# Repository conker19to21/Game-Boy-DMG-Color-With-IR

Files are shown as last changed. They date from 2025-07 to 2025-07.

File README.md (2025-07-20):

This Board is a modified version of <a href="https://github.com/MouseBiteLabs/Game-Boy-DMG-Color/tree/main/DMGC-CPU-01">Bucket Mouse's Original DMGC CPU board</a> which houses the majority of the electronics in the DMGC but adds the IR components and capability as well.

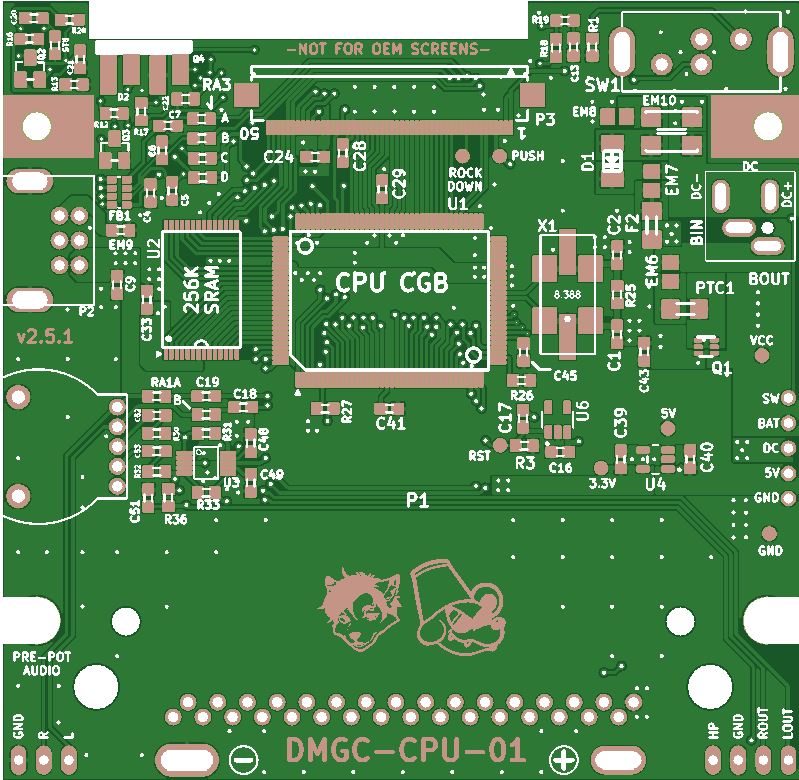
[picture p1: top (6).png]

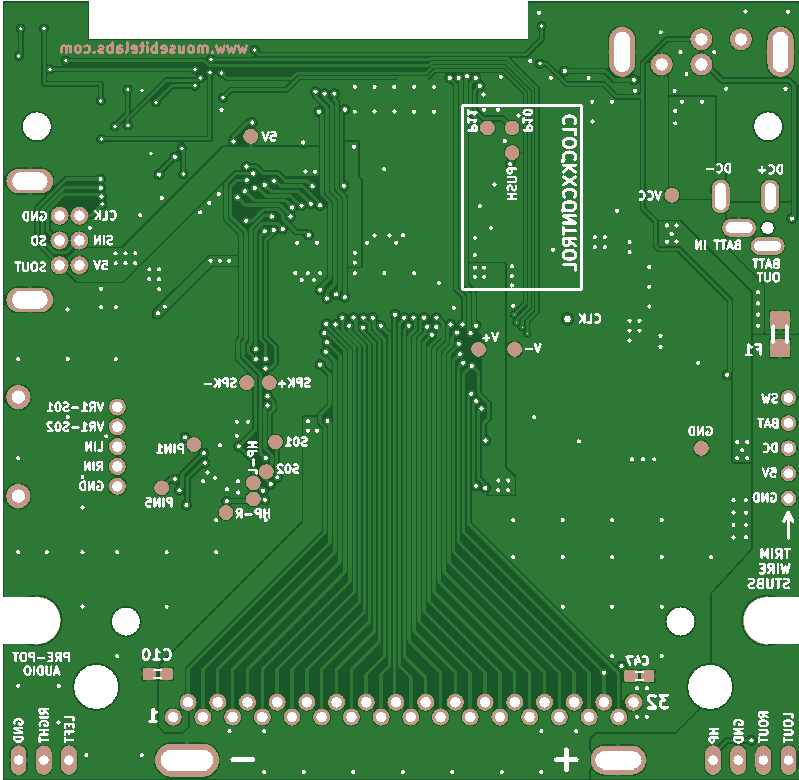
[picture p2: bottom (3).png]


Shoutout to NatalieTheNerd for their amazing Reverse engineering work which was referrenced for this project and can be <a href="https://github.com/nataliethenerd/CGB_ReverseEngineer/tree/main">Found Here!</a>

Additional Major Shout Out goes to EdvinDraw!
A IR shield cutout was designed by EdvinDraw and can be <a href="https://www.thingiverse.com/thing:7093936">Found Here!</a> for use with NON clear DMG shells.

Additionally EdvinDraw had also made a Tutorial how to use and make the IR shield cutout which can be <a href="https://youtu.be/QVl8f0OApuU?si=GgzmjaVQX5JkgJGN">Found Here!</a>

Also note the IR was tested on some clear shells and worked fine without the cutout or IR shield but may still be needed for some.

Download and use the gerber.zip file at your preferred PCB manufacture and use these Board Characteristics for proper fitment.
## Board Characteristics
The gerber zipped folder contains all the gerber files for this board. 

-	Layers: 2
-	Thickness: 1.2 mm
-	Surface Finish: ENIG or HASL
-   **NOTE: When ordering PCBs, add this note to the order: "The file PTH-drl.gbr contains outlines for plated slots. Please add plated slots on the PCB according to this layer."**

*HASL will work, but will potentially be more difficult for soldering fine-pitch parts like the CPU and FFC connector.*

I do not take any credit for Bucket Mouse's Board Design only the modifications done and implementation for the IR components which were added to it.

Be sure to check out Bucket Mouse's Original Github Post on the DMGC project which can be <a href="https://github.com/MouseBiteLabs/Game-Boy-DMG-Color/tree/main">Found Here!</a> and has a Huge breakdown of common issues and solutions to most issues which may occur during the building process.

Version 2.0 of Bucket Mouse's original design introduced a test pad labelled "RST" that connects directly to the /RESET pin. If this pin is pulled to GND, when it's released then the system will reset back to the boot screen. If you wire this pad to a button that connects the pad to GND when pressed, you basically have added a reset button to your DMGC. 

There are also pads near the FFC connector that are added labelled "PUSH" and "ROCK DOWN". These connect to the rocker switch on the DMGC-IPS-01 board (version 2.0 and later). The PUSH pad becomes connected to GND when the rocker switch is pushed in and floats when not pressed (as long as you remove R10 on the DMGC-IPS-01 board). The ROCK_DOWN pad connects to GND when the rocker switch is rocked down, and floats when not pressed (as long as you remove C5 on the DMGC-IPS-01 board).

In a normal configuration, pushing in on the rocker switch will control the button LEDs, and rocking down will swap the Q5 color settings, but if you don't want to use one of these features, then adding a wire from the PUSH or ROCK DOWN pad to RST pad will turn the rocker switch into a reset button for the system for that specific action and replace its normal function.

**CAUTION: Remember to remove R10 or C5 on the IPS board if you plan to use this feature!!!**





## Bill of Materials

Here, I have provided links to components I used personally (or suitable replacements). This BOM is also included in Excel format in the root folder.

| Reference Designators | Qty | Value/Part Number | Package | Description | Comment | Source |
| --- | --- | --- | --- | --- | --- | --- |
| +,- | 2 | | | Battery terminals  | Can be salvaged from DMG instead | [https://retrogamerepairshop.com/collections/dmg-power/products/game-boy-dmg-original-high-quality-replacement-battery-contact-terminals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](https://retrogamerepairshop.com/collections/dmg-power/products/game-boy-dmg-original-high-quality-replacement-battery-contact-terminals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) |
| C1 | 1 | 18pF | 0603 | Capacitor (MLCC) | Should be X5R (or better); at least 1% tolerance; at least 16V | [https://www.mouser.com/ProductDetail/YAGEO/CC0603FRNPO9BN180?qs=vTakOoo5QyL0KzYUzHPSUw%3D%3D](https://www.mouser.com/ProductDetail/YAGEO/CC0603FRNPO9BN180?qs=vTakOoo5QyL0KzYUzHPSUw%3D%3D) |
| C2 | 1 | 27pF | 0603 | Capacitor (MLCC) | Should be X5R (or better); at least 1% tolerance; at least 16V | [https://www.mouser.com/ProductDetail/603-C0603FRNPO9BN270](https://www.mouser.com/ProductDetail/603-C0603FRNPO9BN270) |
| C4 | 1 | 22pF | 0603 | Capacitor (MLCC) | | [https://www.mouser.com/ProductDetail/YAGEO/CC0603JRNPO9BN220?qs=vTakOoo5QyIVMYOUTI%2F4zA%3D%3D](https://www.mouser.com/ProductDetail/YAGEO/CC0603JRNPO9BN220?qs=vTakOoo5QyIVMYOUTI%2F4zA%3D%3D) |
| C5, C6, C7 | 3 | 100pF | 0603 | Capacitor (MLCC) | | [https://www.mouser.com/ProductDetail/YAGEO/CC0603JPNPO9BN101?qs=7s%252B3O6pAiyAo%2FUxNqKltRA%3D%3D](https://www.mouser.com/ProductDetail/YAGEO/CC0603JPNPO9BN101?qs=7s%252B3O6pAiyAo%2FUxNqKltRA%3D%3D) |
| C9, C10, C29, C33, C41, C45 | 6 | 0.01uF | 0603 | Capacitor (MLCC) | Should be X5R (or better), at least 16V | [https://www.mouser.com/ProductDetail/KEMET/C0603C103J5RACTU?qs=BimOss5pjlFJEfKhlb7g1g%3D%3D](https://www.mouser.com/ProductDetail/KEMET/C0603C103J5RACTU?qs=BimOss5pjlFJEfKhlb7g1g%3D%3D) |
| C16, C17, C18, C19, C39, C40, C48, C49, C51 | 9 | 1uF | 0603 | Capacitor (MLCC) | Should be X5R (or better), at least 16V | [https://www.mouser.com/ProductDetail/KEMET/C0603C105K4RACTU?qs=STjISULpmtZNMAZGR4X39Q%3D%3D](https://www.mouser.com/ProductDetail/KEMET/C0603C105K4RACTU?qs=STjISULpmtZNMAZGR4X39Q%3D%3D) |
| C24, C28, C43, C52, C53 | 5 | 0.1uF | 0603 | Capacitor (MLCC) | Should be X5R (or better), at least 16V | [https://www.mouser.com/ProductDetail/?qs=l5k%252BbMnNDknCtKnMv1oEgA%3D%3D](https://www.mouser.com/ProductDetail/?qs=l5k%252BbMnNDknCtKnMv1oEgA%3D%3D) |
| C47 | 1 | 150pF | 0603 | Capacitor (MLCC) | | [https://www.mouser.com/ProductDetail/KEMET/C0603C151J5GACTU?qs=V6nSPVTm7vxbAvL0weNH%252BQ%3D%3D](https://www.mouser.com/ProductDetail/KEMET/C0603C151J5GACTU?qs=V6nSPVTm7vxbAvL0weNH%252BQ%3D%3D) |
| D1 | 1 | PMEG2010AEH | SOD-123 | Schottky diode | Most schottky diodes should be suitable (at least 1A, 16V) | [https://www.mouser.com/ProductDetail/?qs=LOCUfHb8d9u7lcjEnyhX1g%3D%3D](https://www.mouser.com/ProductDetail/?qs=LOCUfHb8d9u7lcjEnyhX1g%3D%3D) |
| DC | 1 | | | DC jack | | Salvaged (DMG) |
| EM6-EM8 | 3 | FBMH2012HM221-T | 0805 | Filter | | https://mou.sr/3YT6y8F |
| EM9 | 1 | BLM18BD102SN1D | 0603 | Filter | | [https://www.mouser.com/ProductDetail/Murata-Electronics/BLM18BD102SN1D?qs=h3IWXJJGQQWi4eZyJq6ScQ%3D%3D](https://www.mouser.com/ProductDetail/Murata-Electronics/BLM18BD102SN1D?qs=h3IWXJJGQQWi4eZyJq6ScQ%3D%3D) |
| EM10 | 1 | 744235601 | | Common mode filter | Can be salvaged from GBC instead | [https://www.mouser.com/ProductDetail/Wurth-Elektronik/744235601?qs=BXmE%252BJ0Y7xYO4MPd53j2NQ%3D%3D](https://www.mouser.com/ProductDetail/Wurth-Elektronik/744235601?qs=BXmE%252BJ0Y7xYO4MPd53j2NQ%3D%3D) |
| F1 | 1 | 2.5A | 1206 | Fuse | | [https://www.mouser.com/ProductDetail/Panasonic/ERB-RG2R50V?qs=Z3CaLxJiOJK8SjHyp%252BdV%2FQ%3D%3D](https://www.mouser.com/ProductDetail/Panasonic/ERB-RG2R50V?qs=Z3CaLxJiOJK8SjHyp%252BdV%2FQ%3D%3D) |
| F2 | 1 | 1A | 1206 | Fuse | | [https://www.mouser.com/ProductDetail/Littelfuse/0466001.NR?qs=ar9f0rk5DXDy6tpNfF8WnQ%3D%3D](https://www.mouser.com/ProductDetail/Littelfuse/0466001.NR?qs=ar9f0rk5DXDy6tpNfF8WnQ%3D%3D) |
| FB1 | 1 | BLA31AG601SN4D | 1206 | Ferrite Bead | | [https://www.mouser.com/ProductDetail/Murata-Electronics/BLA31AG601SN4D?qs=2ahBf5rJw09FDcUVkQibEg%3D%3D](https://www.mouser.com/ProductDetail/Murata-Electronics/BLA31AG601SN4D?qs=2ahBf5rJw09FDcUVkQibEg%3D%3D) |
| P1 | 1 | | | Cart connector | Can be salvaged from DMG instead | [https://www.aliexpress.com/item/3256802533298738.html?spm=a2g0o.order_list.0.0.5ee21802yek6HF](https://www.aliexpress.com/item/3256802533298738.html?spm=a2g0o.order_list.0.0.5ee21802yek6HF) |
| P2 | 1 | | | Link port | | Salvaged (DMG) |
| P3 | 1 | 62684-502100AHLF  | | FFC connector | | [https://www.mouser.com/ProductDetail/?qs=HL%252BYNjdyZ0vzwc9E0QYY2g%3D%3D](https://www.mouser.com/ProductDetail/?qs=HL%252BYNjdyZ0vzwc9E0QYY2g%3D%3D) |
| PTC1 | 1 | 1.1A Hold | 1206 | Resettable Fuse | | [https://www.mouser.com/ProductDetail/Littelfuse/1206L110THYR?qs=CPcc0c%2Fon9HuH5Zb2mgbPg%3D%3D](https://www.mouser.com/ProductDetail/Littelfuse/1206L110THYR?qs=CPcc0c%2Fon9HuH5Zb2mgbPg%3D%3D) |
| Q1 | 1 | SI1443EDH | SOT363 | P-channel MOSFET | | [https://www.mouser.com/ProductDetail/Vishay-Semiconductors/SI1443EDH-T1-GE3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](https://www.mouser.com/ProductDetail/Vishay-Semiconductors/SI1443EDH-T1-GE3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) |
| R1 | 1 | 1k | 0603 | Resistor | | [https://www.mouser.com/ProductDetail/YAGEO/RC0603FR-071KL?qs=VU8sRB4EgwApHsk4rF%2F3zg%3D%3D](https://www.mouser.com/ProductDetail/YAGEO/RC0603FR-071KL?qs=VU8sRB4EgwApHsk4rF%2F3zg%3D%3D) |
| R3, R31, R33 | 3 | 18k | 0603 | Resistor | | [https://www.mouser.com/ProductDetail/YAGEO/RC0603FR-1018KL?qs=qpJ%252B%252B%252Bdg6p1T2VMMxU7GeA%3D%3D](https://www.mouser.com/ProductDetail/YAGEO/RC0603FR-1018KL?qs=qpJ%252B%252B%252Bdg6p1T2VMMxU7GeA%3D%3D) |
| R25 | 1 | 1.5M | 0603 | Resistor | Recommended at least 1% tolerance | [https://www.mouser.com/ProductDetail/YAGEO/RC0603FR-071M5L?qs=VU8sRB4EgwAP38Z8qzPx9Q%3D%3D](https://www.mouser.com/ProductDetail/YAGEO/RC0603FR-071M5L?qs=VU8sRB4EgwAP38Z8qzPx9Q%3D%3D) |
| R26 | 1 | 5.6k | 0603 | Resistor | | [https://www.mouser.com/ProductDetail/YAGEO/RC0603FR-075K6L?qs=2cAdsCoAWRHvOVv%2Fp%252BkS0g%3D%3D](https://www.mouser.com/ProductDetail/YAGEO/RC0603FR-075K6L?qs=2cAdsCoAWRHvOVv%2Fp%252BkS0g%3D%3D) |
| R27 | 1 | 100 | 0603 | Resistor | | [https://www.mouser.com/ProductDetail/YAGEO/RC0603FR-07100RL?qs=NEN%2FsE%2FLsvPIwIWKCOS4%2FA%3D%3D](https://www.mouser.com/ProductDetail/YAGEO/RC0603FR-07100RL?qs=NEN%2FsE%2FLsvPIwIWKCOS4%2FA%3D%3D) |
| R36 | 1 | 100k | 0603 | Resistor | | [https://www.mouser.com/ProductDetail/YAGEO/RC0603FR-07100KL?qs=e1ok2LiJcmaihem8Va5%2Fsw%3D%3D](https://www.mouser.com/ProductDetail/YAGEO/RC0603FR-07100KL?qs=e1ok2LiJcmaihem8Va5%2Fsw%3D%3D) |
| R30, R32 | 2 | 47k | 0603 | Resistor | | [https://www.mouser.com/ProductDetail/YAGEO/RC0603FR-1047KL?qs=EiqXWrxQq600ZhhpLJs%252BtA%3D%3D](https://www.mouser.com/ProductDetail/YAGEO/RC0603FR-1047KL?qs=EiqXWrxQq600ZhhpLJs%252BtA%3D%3D) |
| RA1A, RA1B | 2 | 510 | 0603 | Resistor | | [https://www.mouser.com/ProductDetail/YAGEO/RC0603FR-07510RL?qs=gt6vzsuosg04lV7mPQHzdw%3D%3D](https://www.mouser.com/ProductDetail/YAGEO/RC0603FR-07510RL?qs=gt6vzsuosg04lV7mPQHzdw%3D%3D) |
| RA3A-RA3D | 4 | 270 | 0603 | Resistor | | [https://www.mouser.com/ProductDetail/YAGEO/RC0603FR-07270RL?qs=diQw95jMAePl%252BPNr4oNP6Q%3D%3D](https://www.mouser.com/ProductDetail/YAGEO/RC0603FR-07270RL?qs=diQw95jMAePl%252BPNr4oNP6Q%3D%3D) |
| SW1 | 1 | | | Power switch | | Salvaged (DMG) |
| U1 | 1 | GBC CPU | QFP-128 | CPU | | Salvaged (GBC) |
| U2 | 1 | LH52256CVTXIZ | TSOP-28 | RAM | Replacement: https://mou.sr/3f8G0Mi | Salvaged (GBC) |
| U3 | 1 | LM4853 | VSSOP-10 | Audio amplifier | | [https://www.mouser.com/ProductDetail/Texas-Instruments/LM4853MM-NOPB?qs=QbsRYf82W3F2psFI2da2Dw%3D%3D](https://www.mouser.com/ProductDetail/Texas-Instruments/LM4853MM-NOPB?qs=QbsRYf82W3F2psFI2da2Dw%3D%3D) |
| U4 | 1 | NCP161ASN330T1G | SOT23-5 | LDO | Can also use TLV70233QDBVRQ1, probably | [https://www.mouser.com/ProductDetail/863-NCP161ASN330T1G](https://www.mouser.com/ProductDetail/863-NCP161ASN330T1G) |
| U6 | 1 | TPS3840DL35 | SOT23-5 | Supervisory IC | Could feasibly use TPS3840DL37 or 40 if 35 is out of stock | [https://www.mouser.com/ProductDetail/Texas-Instruments/TPS3840DL35DBVR?qs=7MVldsJ5UawbjRj7dP73rA%3D%3D](https://www.mouser.com/ProductDetail/Texas-Instruments/TPS3840DL35DBVR?qs=7MVldsJ5UawbjRj7dP73rA%3D%3D) |
| VR1 | 1 | 10k | | Volume wheel | Can be salvaged from DMG instead | [https://aliexpi.com/qg1M](https://aliexpi.com/qg1M) |
| X1 | 1 | 8.388608MHz | 7.5X5-4-PAD | Crystal oscillator | Potential replacement (not very space-friendly): https://mou.sr/3D5AUbH | Salvaged (GBC) |
| C13 | 1 | 470nF | 0603 Capacitor | Capacitor (MLCC) |  | [https://mou.sr/4cTTRzx](https://mou.sr/4cTTRzx)
| C20 | 1 | 15nF | 0603 Capacitor | Capacitor (MLCC) |  | [https://mou.sr/4jKsSIQ](https://mou.sr/4jKsSIQ)
| C21 | 1 | 1uF | 0603 Capacitor | Capacitor (MLCC) |  | [https://mou.sr/47lY3oP](https://mou.sr/47lY3oP)
| C22 | 1 | 33pF | 0603 Capacitor | Capacitor (MLCC) |  | [https://mou.sr/4cMeVrs](https://mou.sr/4cMeVrs)
| D2 | 1 | GL381 |  | 3mm Infrared LED |  | Salvaged (GBC)
| Q2, Q3 | 2  | 2SC4081 | SOT-323 / SC-70 |  |  | [https://mou.sr/3XxVZGQ](https://mou.sr/3XxVZGQ) 
| Q4 | 1 | PT380F |  | 3mm Phototransistor |  | Salvaged (GBC)
| R12 | 1 | 4.7k ohm | 0603 Capacitor | Resistor |  |  [https://mou.sr/41PpIxl](https://mou.sr/41PpIxl)
| R13, R16 | 2 | 33k ohm | 0603 Capacitor | Resistor |  |  [https://mou.sr/3DVwgBw](https://mou.sr/3DVwgBw)
| R15 | 1 | 1M ohm | 0603 Capacitor | Resistor |  |  [https://mou.sr/4iLYdL4](https://mou.sr/4iLYdL4)
| R17 | 1 | 200k ohm | 0603 Capacitor | Resistor |  |  [https://mou.sr/4cdZFn6](https://mou.sr/4cdZFn6)
| R18 | 1 | 150 ohm | 0603 Capacitor | Resistor |  |  [https://mou.sr/4l9UBnU](https://mou.sr/4l9UBnU)
| R19 | 1 | 1k ohm | 0603 Capacitor | Resistor |  |  [https://mou.sr/3U0EvS4](https://mou.sr/3U0EvS4)
| R20 | 1 | 2k ohm | 0603 Capacitor | Resistor |  |  [https://mou.sr/4j6GOfR](https://mou.sr/4j6GOfR)
| GBC IR Shield | 1 | | | IR Shield |  |  Salvaged (GBC)

## License
<br />This work is licensed under a <a rel="license" href="http://creativecommons.org/licenses/by-sa/4.0/">Creative Commons Attribution-ShareAlike 4.0 International License</a>. You are able to copy and redistribute the material in any medium or format, as well as remix, transform, or build upon the material for any purpose (even commercial) - but you **must** give appropriate credit, provide a link to the license, and indicate if any changes were made.

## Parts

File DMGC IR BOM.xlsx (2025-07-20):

CPU-01 IR | C13 |  | 470nF | 0603 Capacitor | Capacitor (MLCC) |  | https://mou.sr/4cTTRzx
 | C20 |  | 15nF | 0603 Capacitor | Capacitor (MLCC) |  | https://mou.sr/4jKsSIQ
 | C21 |  | 1uF | 0603 | Capacitor (MLCC) |  | https://www.mouser.com/ProductDetail/KEMET/C0603C105K4RACTU?qs=STjISULpmtZNMAZGR4X39Q%3D%3D
 | C22 |  | 33pF | 0603 Capacitor | Capacitor (MLCC) |  | https://mou.sr/4cMeVrs
 | D2 |  | GL381 | 3mm Infrared LED |  |  | Salvaged (GBC)
 | Q2 |  | 2SC4081 | SOT-323 / SC-70 |  |  | https://mou.sr/3XxVZGQ
 | Q3 |  | 2SC4081 | SOT-323 / SC-70 |  |  | https://mou.sr/3XxVZGQ
 | Q4 |  | PT380F | 3mm Phototransistor |  |  | Salvaged (GBC)
 | R12 |  | 4.7k ohm | 0603 Capacitor | Resistor |  | https://mou.sr/41PpIxl
 | R13 |  | 33k ohm | 0603 Capacitor | Resistor |  | https://mou.sr/3DVwgBw
 | R15 |  | 1M ohm | 0603 Capacitor | Resistor |  | https://mou.sr/4iLYdL4
 | R16 |  | 33k ohm | 0603 Capacitor | Resistor |  | https://mou.sr/3DVwgBw
 | R17 |  | 200k ohm | 0603 Capacitor | Resistor |  | https://mou.sr/4cdZFn6
 | R18 |  | 150 ohm | 0603 Capacitor | Resistor |  | https://mou.sr/4l9UBnU
 | R19 |  | 1k ohm | 0603 | Resistor |  | https://www.mouser.com/ProductDetail/YAGEO/RC0603FR-071KL?qs=VU8sRB4EgwApHsk4rF%2F3zg%3D%3D
 | R20 |  | 2k ohm | 0603 Capacitor | Resistor |  | https://mou.sr/4j6GOfR
CPU-01 | -/+ | 2 |  |  | Battery terminals | Can be salvaged from DMG instead | https://retrogamerepairshop.com/collections/dmg-power/products/game-boy-dmg-original-high-quality-replacement-battery-contact-terminals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
 | C1 | 1 | 18pF | 603 | Capacitor (MLCC) | Should be X5R (or better); at least 1% tolerance; at least 16V | https://www.mouser.com/ProductDetail/YAGEO/CC0603FRNPO9BN180?qs=vTakOoo5QyL0KzYUzHPSUw%3D%3D
 | C2 | 1 | 27pF | 603 | Capacitor (MLCC) | Should be X5R (or better); at least 1% tolerance; at least 16V | https://www.mouser.com/ProductDetail/603-C0603FRNPO9BN270
 | C4 | 1 | 22pF | 603 | Capacitor (MLCC) |  | https://www.mouser.com/ProductDetail/YAGEO/CC0603JRNPO9BN220?qs=vTakOoo5QyIVMYOUTI%2F4zA%3D%3D
 | C5, C6, C7 | 3 | 100pF | 603 | Capacitor (MLCC) |  | https://www.mouser.com/ProductDetail/YAGEO/CC0603JPNPO9BN101?qs=7s%252B3O6pAiyAo%2FUxNqKltRA%3D%3D
 | C9, C10, C29, C33, C41, C45 | 6 | 0.01uF | 603 | Capacitor (MLCC) | Should be X5R (or better), at least 16V | https://www.mouser.com/ProductDetail/KEMET/C0603C103J5RACTU?qs=BimOss5pjlFJEfKhlb7g1g%3D%3D
 | C16, C17, C18, C19, C39, C40, C48, C49, C51 | 9 | 1uF | 603 | Capacitor (MLCC) | Should be X5R (or better), at least 16V | https://www.mouser.com/ProductDetail/KEMET/C0603C105K4RACTU?qs=STjISULpmtZNMAZGR4X39Q%3D%3D
 | C24, C28, C43, C52, C53 | 5 | 0.1uF | 603 | Capacitor (MLCC) | Should be X5R (or better), at least 16V | https://www.mouser.com/ProductDetail/?qs=l5k%252BbMnNDknCtKnMv1oEgA%3D%3D
 | C47 | 1 | 150pF | 603 | Capacitor (MLCC) |  | https://www.mouser.com/ProductDetail/KEMET/C0603C151J5GACTU?qs=V6nSPVTm7vxbAvL0weNH%252BQ%3D%3D
 | D1 | 1 | PMEG2010AEH | SOD-123 | Schottky diode | Most schottky diodes should be suitable (at least 1A, 16V) | https://www.mouser.com/ProductDetail/?qs=LOCUfHb8d9u7lcjEnyhX1g%3D%3D
 | DC | 1 |  |  | DC jack |  | Salvaged (DMG)
 | EM6-EM8 | 3 | FBMH2012HM221-T | 805 | Filter |  | https://mou.sr/3YT6y8F
 | EM9 | 1 | BLM18BD102SN1D | 603 | Filter |  | https://www.mouser.com/ProductDetail/Murata-Electronics/BLM18BD102SN1D?qs=h3IWXJJGQQWi4eZyJq6ScQ%3D%3D
 | EM10 | 1 | 744235601 |  | Common mode filter | Can be salvaged from GBC instead | https://www.mouser.com/ProductDetail/Wurth-Elektronik/744235601?qs=BXmE%252BJ0Y7xYO4MPd53j2NQ%3D%3D
 | F1 | 1 | 2.5A | 1206 | Fuse |  | https://www.mouser.com/ProductDetail/Panasonic/ERB-RG2R50V?qs=Z3CaLxJiOJK8SjHyp%252BdV%2FQ%3D%3D
 | F2 | 1 | 1A | 1206 | Fuse |  | https://www.mouser.com/ProductDetail/Littelfuse/0466001.NR?qs=ar9f0rk5DXDy6tpNfF8WnQ%3D%3D
 | FB1 | 1 | BLA31AG601SN4D | 1206 | Ferrite Bead |  | https://www.mouser.com/ProductDetail/Murata-Electronics/BLA31AG601SN4D?qs=2ahBf5rJw09FDcUVkQibEg%3D%3D
 | P1 | 1 |  |  | Cart connector | Can be salvaged from DMG instead | https://www.aliexpress.com/item/3256802533298738.html?spm=a2g0o.order_list.0.0.5ee21802yek6HF
 | P2 | 1 |  |  | Link port |  | Salvaged (DMG)
 | P3 | 1 | 62684-502100AHLF |  | FFC connector |  | https://www.mouser.com/ProductDetail/?qs=HL%252BYNjdyZ0vzwc9E0QYY2g%3D%3D
 | PTC1 | 1 | 1.1A Hold | 1206 | Resettable Fuse |  | https://www.mouser.com/ProductDetail/Littelfuse/1206L110THYR?qs=CPcc0c%2Fon9HuH5Zb2mgbPg%3D%3D
 | Q1 | 1 | SI1443EDH | SOT363 | P-channel MOSFET |  | https://www.mouser.com/ProductDetail/Vishay-Semiconductors/SI1443EDH-T1-GE3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
 | R1 | 1 | 1k | 603 | Resistor |  | https://www.mouser.com/ProductDetail/YAGEO/RC0603FR-071KL?qs=VU8sRB4EgwApHsk4rF%2F3zg%3D%3D
 | R3, R31, R33 | 3 | 18k | 603 | Resistor |  | https://www.mouser.com/ProductDetail/YAGEO/RC0603FR-1018KL?qs=qpJ%252B%252B%252Bdg6p1T2VMMxU7GeA%3D%3D
 | R25 | 1 | 1.5M | 603 | Resistor | Recommended at least 1% tolerance | https://www.mouser.com/ProductDetail/YAGEO/RC0603FR-071M5L?qs=VU8sRB4EgwAP38Z8qzPx9Q%3D%3D
 | R26 | 1 | 5.6k | 603 | Resistor |  | https://www.mouser.com/ProductDetail/YAGEO/RC0603FR-075K6L?qs=2cAdsCoAWRHvOVv%2Fp%252BkS0g%3D%3D
 | R27 | 1 | 100 | 603 | Resistor |  | https://www.mouser.com/ProductDetail/YAGEO/RC0603FR-07100RL?qs=NEN%2FsE%2FLsvPIwIWKCOS4%2FA%3D%3D
 | R36 | 1 | 100k | 603 | Resistor |  | https://www.mouser.com/ProductDetail/YAGEO/RC0603FR-07100KL?qs=e1ok2LiJcmaihem8Va5%2Fsw%3D%3D
 | R30, R32 | 2 | 47k | 603 | Resistor |  | https://www.mouser.com/ProductDetail/YAGEO/RC0603FR-1047KL?qs=EiqXWrxQq600ZhhpLJs%252BtA%3D%3D
 | RA1A, RA1B | 2 | 510 | 603 | Resistor |  | https://www.mouser.com/ProductDetail/YAGEO/RC0603FR-07510RL?qs=gt6vzsuosg04lV7mPQHzdw%3D%3D
 | RA3A-RA3D | 4 | 270 | 603 | Resistor |  | https://www.mouser.com/ProductDetail/YAGEO/RC0603FR-07270RL?qs=diQw95jMAePl%252BPNr4oNP6Q%3D%3D
 | SW1 | 1 |  |  | Power switch |  | Salvaged (DMG)
 | U1 | 1 | GBC CPU | QFP-128 | CPU |  | Salvaged (GBC)
 | U2 | 1 | LH52256CVTXIZ | TSOP-28 | RAM | Replacement: https://mou.sr/3f8G0Mi | Salvaged (GBC)
 | U3 | 1 | LM4853 | VSSOP-10 | Audio amplifier |  | https://www.mouser.com/ProductDetail/Texas-Instruments/LM4853MM-NOPB?qs=QbsRYf82W3F2psFI2da2Dw%3D%3D
 | U4 | 1 | NCP161ASN330T1G | SOT23-5 | LDO | Can also use TLV70233QDBVRQ1, probably | https://www.mouser.com/ProductDetail/863-NCP161ASN330T1G
 | U6 | 1 | TPS3840DL35 | SOT23-5 | Supervisory IC | Could feasibly use TPS3840DL37 or 40 if 35 is out of stock | https://www.mouser.com/ProductDetail/Texas-Instruments/TPS3840DL35DBVR?qs=7MVldsJ5UawbjRj7dP73rA%3D%3D
 | VR1 | 1 | 10k |  | Volume wheel | Can be salvaged from DMG instead | https://aliexpi.com/qg1M
 | X1 | 1 | 8.388608MHz | 7.5X5-4-PAD | Crystal oscillator | Potential replacement (not very space-friendly): https://mou.sr/3D5AUbH | Salvaged (GBC)

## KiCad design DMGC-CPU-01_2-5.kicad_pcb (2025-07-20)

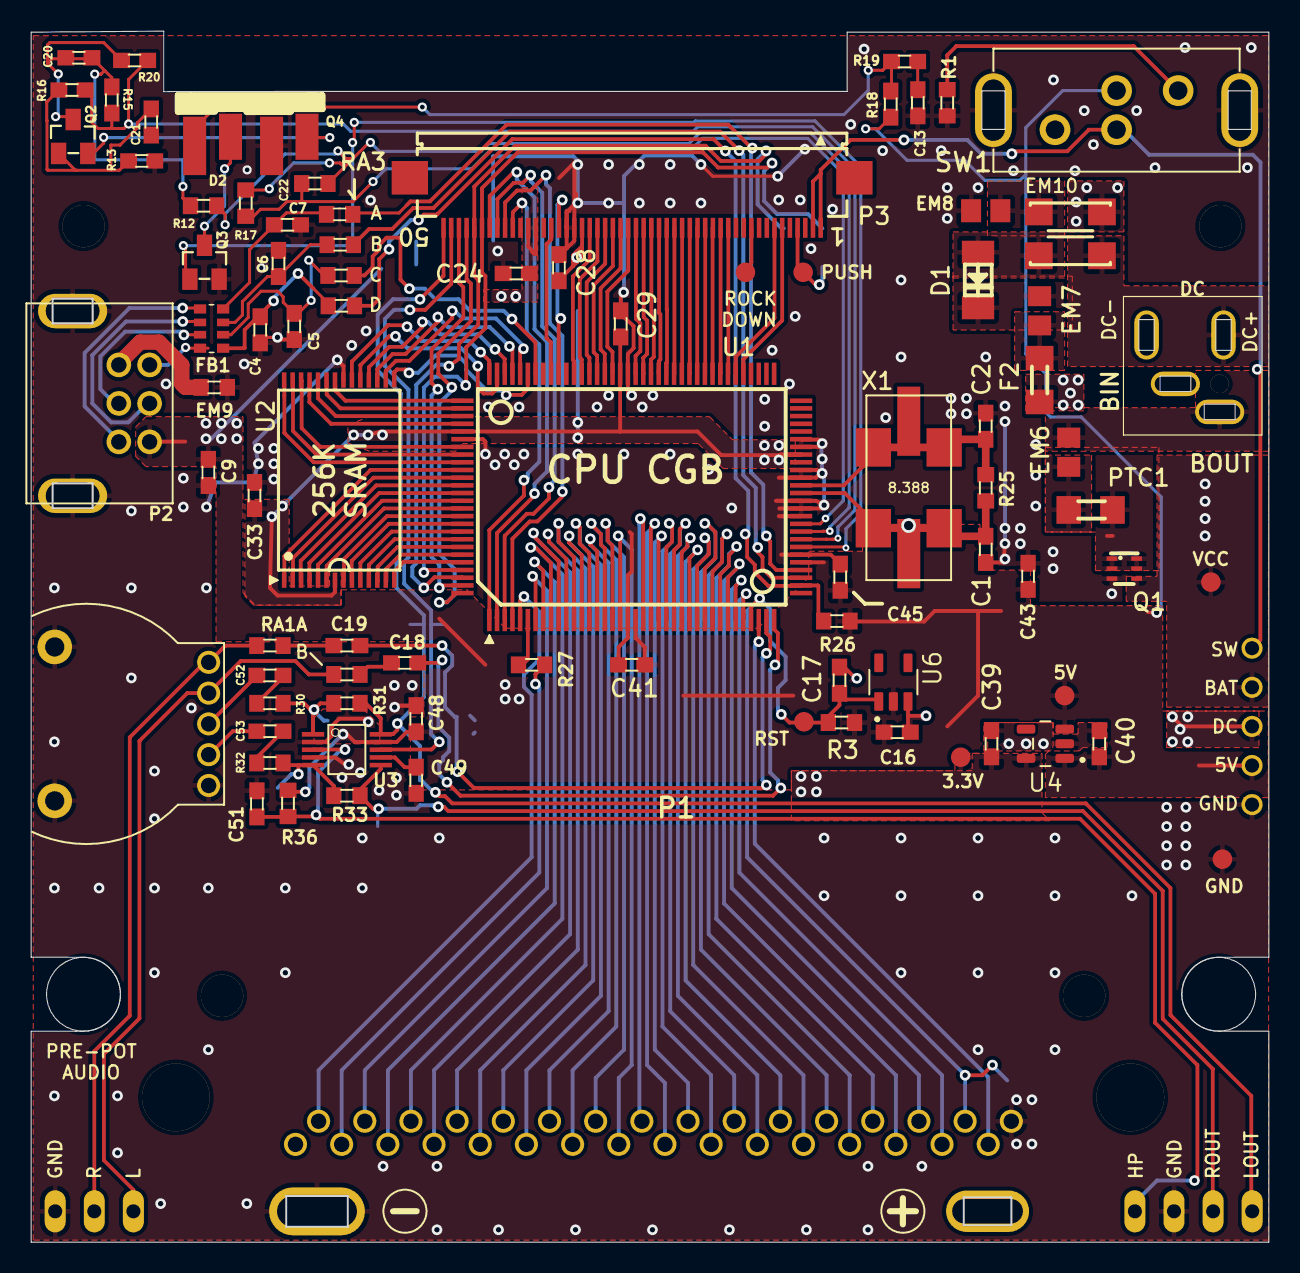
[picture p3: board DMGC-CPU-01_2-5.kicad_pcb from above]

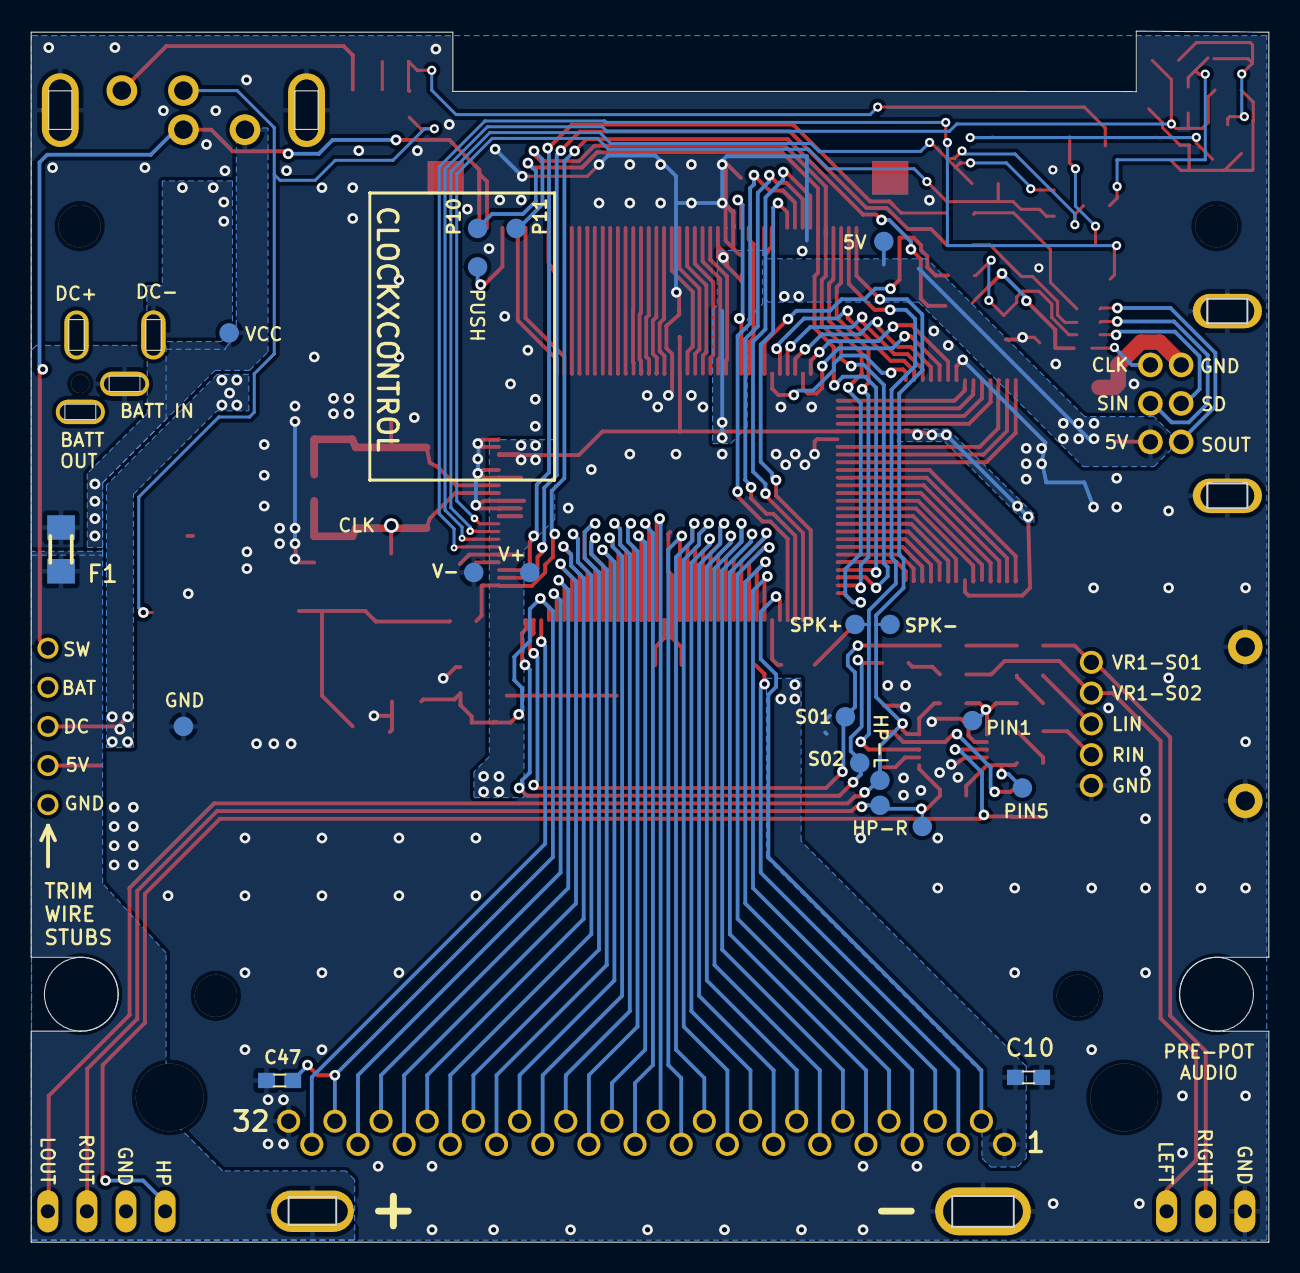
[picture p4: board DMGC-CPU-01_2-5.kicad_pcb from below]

Board: 2 copper layers, 80.4 x 78.7 mm, 125 parts (20 on the bottom side), 143 nets.

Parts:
3.3V, 5V: PTR1B1,27; B1,27_385
+0: DMG_BAT_POS
-0: DMG_BAT_NEG
@HOLE0, @HOLE1, @HOLE2, @HOLE3, @HOLE4, @HOLE5, @HOLE6, @HOLE7: (no value)
AUDIO0: JP4
C1: 18pF; C0603
C2: 27pF; C0603
C4: 22pF; C0603
C5, C6, C7: 100pF; C0603
C9, C10, C29, C33, C41, C45: 0.01uF; C0603
C13: 0.47uF; C0603
C16, C17, C18, C19, C21, C39, C40, C48, C49, C51: 1uF; C0603
C20: 0.015uF; C0603
C22: 33pF; R0603
C24, C28, C43: 0.1uF; C0603
C47: 150pF; C0603
C52, C53: 100nF; C0603
D1: CGRM4001-G; SOD-123_MINI-SMA_210
D2, D2#2: GL381
DC: DMG_DCJACK
EM6, EM7, EM8: BLM21P221SG; R0805
EM9: BLM21P221SG; R0603
EM10: ACM4532
F1: 2.5A; R1206
F2: 1A; R1206
FB1: 4W601; EXB38V_342
GND: PTR1B1,27; B1,27_385
GND_BACK0: PTR1B1,27; B1,27_385
JP1: JP5
JP2: JP2
LOUT0: PTR1B1,27; B1,27_385
P1: DMG_CART
P2: LINKPORTDMG-LINK-SHORT; DMG_EXT
P3: GBC_LCDH; 62684-502100AHLF
P10, P11: PTR1B1,27; B1,27_385
PIN1, PIN5: PTR1B1,27; B1,27_385
PSH_IN0: PTR1B1,27; B1,27_385
PTC1: 1.1A; R1206
PUSH: PTR1B1,27; B1,27_385
Q1: SI1401EDH; SOT363_INFINEON_396
Q2, Q2#2, Q2#3, Q3, Q3#2, Q3#3: 2SC4081
Q4, Q4#2: PT380F
R1: 1k; R0603
R3, R31, R33: 18k; R0603
R12: 4.7k; R0603
R13, R16: 33k; C0603
R15: 1M; C0603
R17: 200k; R0603
R18: 150; C0603
R19: 1k; C0603
R20: 2k; C0603
R25: 1.5M; R0603
R26: 5.6k; R0603
R27: 100; R0603
R30, R32: 47k; R0603
R36: 100k; R0603
RA1A, RA1B0: 510; R0603
RA3A0, RA3B0, RA3C0, RA3D0: 270; R0603
ROCKDOWN0: PTR1B1,27; B1,27_385
ROUT0, ROUT1: PTR1B1,27; B1,27_385
RST: PTR1B1,27; B1,27_385
S01, S02: PTR1B1,27; B1,27_385
SPK+: PTR1B1,27; B1,27_385
SPK-: PTR1B1,27; B1,27_385
SW1: DMG_SW
U1: GBC_CPU; QFP-128
U2: LH52256CVTCZ; TSOP1-28
U3: LM4853; VSSOP10
U4: TLV70233QDBVRQ1; SOT95P280X145-5N
U6: TPS3840; SOT-23-5
UNK3.3V_BACK0, UNK5V_BACK0: PTR1B1,27; B1,27_385
V-: PTR1B1,27; B1,27_385
VCC: PTR1B1,27; B1,27_385
VCC_BACK0: PTR1B1,27; B1,27_385
VR1: DMG_VOL
X1: 8.388608MHZ12SMX-B-4-PAD; 7.5X5-4-PAD

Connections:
+3V3: 3.3V.TP, C28.2, C29.1, C33.1, C39.1, P3.32 (1), U1.57 (~\NMI), U1.85 (VDD3@85), U1.107 (VDD3@107), U2.7 (VCC), U4.5 (OUT), UNK3.3V_BACK0.TP
+5V: 5V.TP, C9.1, C10.1, C16.1, C24.1, C40.1, C41.1, C43.1, C45.1, C48.1, JP1.2, P1.1 (VCC), P2.+5V, P3.38 (1), P3.39 (1), R3.1, R18.1, R26.2, R36.2, SW1.P$3 (3), U1.20 (VDD5@20), U1.43 (VDD5@43), U3.9 (VDD), U4.1 (IN), U4.3 (EN), U6.2 (VDD), UNK5V_BACK0.TP
/A0: P1.6 (A0), U1.9 (A0)
/A1: P1.7 (A1), U1.10 (A1)
/A2: P1.8 (A2), U1.11 (A2)
/A3: P1.9 (A3), U1.12 (A3)
/A4: P1.10 (A4), U1.13 (A4)
/A5: P1.11 (A5), U1.14 (A5)
/A6: P1.12 (A6), U1.15 (A6)
/A7: P1.13 (A7), U1.16 (A7)
/A8: P1.14 (A8), U1.17 (A8)
/A9: P1.15 (A9), Q2#2.2 (S), Q4#2.5, U1.18 (A9)
/A10: P1.16 (A10), U1.21 (A10)
/A11: P1.17 (A11), U1.22 (A11)
/A12: P1.18 (A12), U1.23 (A12)
/A13: P1.19 (A13), U1.24 (A13)
/A14: P1.20 (A14), U1.25 (A14)
/A15: P1.21 (A15), U1.26 (A15)
/BATT: +0.P$1, F1.1
/CK1: C1.1, D2.5, R18.2, R19.1, R25.1, U1.52 (CK1), X1.1, X1.4, X1.5
/CK2: C2.1, R25.2, U1.53 (CK2), X1.2, X1.3, X1.6
/CLS: P3.7 (1), U1.70 (CLS)
/CS: P1.5 (~CS), U1.8 (~CS)
/D0: P1.22 (D0), U1.27 (D0)
/D1: P1.23 (D1), U1.28 (D1)
/D2: P1.24 (D2), U1.29 (D2)
/D3: D2#2.5, P1.25 (D3), Q3#2.3 (D), U1.30 (D3)
/D4: P1.26 (D4), U1.31 (D4)
/D5: P1.27 (D5), U1.32 (D5)
/D6: P1.28 (D6), U1.33 (D6)
/D7: P1.29 (D7), U1.34 (D7)
/DCK: P3.36 (1), U1.94 (DCK)
/DC_JACK: F2.1, JP1.3
/ELP2: FB1.1, P2.OUT
/ELP3: FB1.2 (1), P2.IN
/ELP4: FB1.3 (1), P2.SD
/ELP5: FB1.4 (1), P2.CLK
/HP_SWITCH: AUDIO0.1, C51.1, R36.1, U3.3 (HP_IN)
/LDB0: P3.26 (1), U1.86 (LDB0)
/LDB1: P3.27 (1), U1.87 (LDB1)
/LDB2: P3.28 (1), U1.88 (LDB2)
/LDB3: P3.29 (1), U1.89 (LDB3)
/LDB4: P3.30 (1), U1.90 (LDB4)
/LDB5: P3.31 (1), U1.91 (LDB5)
/LDG0: P3.20 (1), U1.78 (LDG0)
/LDG1: P3.21 (1), U1.79 (LDG1)
/LDG2: P3.22 (1), U1.80 (LDG2)
/LDG3: P3.23 (1), U1.81 (LDG3)
/LDG4: P3.24 (1), U1.82 (LDG4)
/LDG5: P3.25 (1), U1.83 (LDG5)
/LDR0: P3.14 (1), U1.72 (LDR0)
/LDR1: P3.15 (1), U1.73 (LDR1)
/LDR2: P3.16 (1), U1.74 (LDR2)
/LDR3: P3.17 (1), U1.75 (LDR3)
/LDR4: P3.18 (1), U1.76 (LDR4)
/LDR5: P3.19 (1), U1.77 (LDR5)
/LIN_AMP: PIN1.TP, R30.1, R31.2, U3.1 (LIN)
/LP: P3.35 (1), U1.93 (LP)
/MA0: U1.99 (MA0), U2.17 (A0)
/MA1: U1.98 (MA1), U2.16 (A1)
/MA2: U1.97 (MA2), U2.15 (A2)
/MA3: U1.124 (MA3), U2.14 (A3)
/MA4: U1.123 (MA4), U2.13 (A4)
/MA5: U1.122 (MA5), U2.12 (A5)
/MA6: U1.121 (MA6), U2.11 (A6)
/MA7: U1.120 (MA7), U2.10 (A7)
/MA8: U1.115 (MA8), U2.4 (A8)
/MA9: U1.114 (MA9), U2.3 (A9)
/MA10: U1.111 (MA10), U2.28 (A10)
/MA11: U1.113 (MA11), U2.2 (A11)
/MA12: U1.119 (MA12), U2.9 (A12)
/MD0: U1.100 (MD0), U2.18 (DQ0)
/MD1: U1.101 (MD1), U2.19 (DQ1)
/MD2: U1.102 (MD2), U2.20 (DQ2)
/MD3: U1.103 (MD3), U2.22 (DQ3)
/MD4: U1.104 (MD4), U2.23 (DQ4)
/MD5: U1.105 (MD5), U2.24 (DQ5)
/MD6: U1.106 (MD6), U2.25 (DQ6)
/MD7: U1.109 (MD7), U2.26 (DQ7)
/P00: P3.41 (1), U1.1 (P00)
/P01: P3.42 (1), U1.4 (P01)
/P02: P3.43 (1), U1.3 (P02)
/P03: P3.44 (1), U1.2 (P03)
/P10: P3.45 (1), P10.TP, U1.125 (P10)
/P11: P3.46 (1), P11.TP, U1.126 (P11)
/P12: P3.47 (1), U1.128 (P12)
/P13: P3.48 (1), U1.127 (P13)
/PUSH: P3.4 (1), PSH_IN0.TP, PUSH.TP
/R0: Q3.1 (G), U1.45 (R0)
/R1: R15.1, R16.1, R20.1, U1.46 (R1)
/R2: C22.1, R12.2, R17.2, U1.47 (R2)
/R3: C22.2, R17.1, U1.48 (R3)
/R4: RA3C0.2, U1.96 (R4)
/RA0: U1.116 (RA0), U2.5 (A13)
/RA1: U1.118 (RA1), U2.8 (A14)
/RA1-S01: C19.2, RA1A.2
/RA1-S02: C18.2, RA1B0.2
/RD: P1.4 (~RD), U1.7 (~RD)
/RES: C17.1, C47.1, P1.30 (~RST), R3.2, RST.TP, U1.35 (~RESET), U6.1 (~RESET)
/RIN_AMP: PIN5.TP, R32.1, R33.2, U3.5 (RIN)
/ROCK_DOWN: P3.10 (1), ROCKDOWN0.TP
/ROUT: AUDIO0.3, R33.1, ROUT0.TP, ROUT1.TP, U3.6 (ROUT)
/S01: C19.1, S01.TP, U1.37 (S01)
/S02: C18.1, S02.TP, U1.38 (S02)
/SCK: R26.1, RA3D0.2, U1.40 (SCK)
/SIN: RA3B0.2, U1.41 (SIN)
/SOUT: RA3A0.2, U1.42 (SOUT)
/SPK+: P3.49 (1), SPK+.TP, U3.8 (BTL+)
/SPK-: AUDIO0.4, LOUT0.TP, P3.50 (1), R31.1, SPK-.TP, U3.10 (LOUT/BTL-)
/SPL: P3.13 (1), U1.71 (SPL)
/SPS: P3.6 (1), U1.69 (SPS)
/VCC_SW: JP1.5, P3.1, P3.2 (1), SW1.P$1 (1)
/VIN: P1.31 (SND), U1.36 (VIN)
/VR1-S01: JP2.2, RA1A.1, VR1.P$5 (VR1-S01)
/VR1-S02: JP2.3, RA1B0.1, VR1.P$4 (VR1-S02)
/WR: P1.3 (~WR), R27.2
/~CS1: U1.110 (~\CS1), U2.27 (~CE)
/~MRD: U1.112 (~\MRD), U2.1 (~OE)
/~MWR: U1.117 (~\MWR), U2.6 (~WE)
GND: -0.P$1, AUDIO0.2, C1.2, C2.2, C4.2, C5.2, C6.2, C7.2, C9.2, C10.2, C13.1, C16.2, C17.2, C21.2, C24.2, C28.1, C29.2, C33.2, C39.2, C40.2, C41.2, C43.2, C45.2, C47.2, C48.2, C49.2, C51.2, EM8.2, EM9.2, GND.TP, GND_BACK0.TP, JP1.1, JP2.1, P1.32 (GND), P2.SHIELD, P2.SHIELD1, P3.33 (1), P3.34 (1), Q1.3 (G), Q3#3.2 (S), Q4.5, R1.2, R13.2, SW1.P$7, SW1.P$8, U1.19 (GND@19), U1.44 (GND@44), U1.49 (TEST0), U1.50 (TEST1), U1.51 (TEST2), U1.54 (PSMD0), U1.55 (PSMD1), U1.58 (~MCS0), U1.59 (~MCS1), U1.84 (GND@84), U1.108 (GND@108), U2.21 (GND), U3.2 (SHTDWN), U3.4 (GND), U4.2 (GND), U6.3 (GND), V-.TP, VR1.P$1 (GND), VR1.P$6, VR1.P$7
unnamed: C13.2, C20.2, C52.2, Q2#3.3 (D), R19.2, R20.2, R30.2
unnamed: C20.1, C53.2, R12.1, R15.2, R32.2
unnamed: D1.A, EM10.4
unnamed: D1.C, EM7.1
unnamed: DC.2 (DC), EM10.1
unnamed: DC.1 (GND), EM10.2
unnamed: DC.3 (SWA), EM6.1
unnamed: DC.4 (SWB), F1.2
unnamed: EM6.2, PTC1.2
unnamed: EM7.2, F2.2
unnamed: EM9.1, P2.GND
unnamed: EM8.1, EM10.3
unnamed: C7.1, FB1.8 (2), RA3A0.1
unnamed: C6.1, FB1.7 (2), RA3B0.1
unnamed: C5.1, FB1.6 (2), RA3C0.1
unnamed: C4.1, FB1.5 (2), RA3D0.1
unnamed: PTC1.1, Q1.1 (D1), Q1.2 (D2), Q1.5 (D5), Q1.6 (D6)
unnamed: R1.1, SW1.P$4 (4)
unnamed: R27.1, U1.6 (~WR)
unnamed: C49.1, U3.7 (BYPASS)
unnamed: C52.1, VR1.P$3 (LIN)
unnamed: C53.1, VR1.P$2 (RIN)
VCC: JP1.4, Q1.4 (S), SW1.P$2 (2), VCC.TP, VCC_BACK0.TP
